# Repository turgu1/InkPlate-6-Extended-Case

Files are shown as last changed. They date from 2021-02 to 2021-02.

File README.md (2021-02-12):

# InkPlate-6-Extended-Case

This is a change to the current InkPlate-6 case to add a small electronic board with push buttons below the mainboard. To do it, I took the original design from e-Radionica and extended a side of it, so the original portion of the case remains unchanged. The `Mechanical CAD` folder contains the complete STEP format design as well as the STL files ready for 3D printing. The `Electronics` folder contains the Gerber files for the preparation of the pc-board, as well as the schematic in PDF. I have used **OnShape** and **KiCAD** to complete this project.

- For the STL files, dimensions are in millimeters. 
- Six buttons must be printed as well as the top and bottom casing. The buttons may have to be adjusted in size depending on the 3D printing results.
- The connection with the MCU23017 is done using wirewrap wires (or a flat cable) that are soldered at both ends using the following configuration (beware that the corresponding buttons numbers are inverted in the sequence):

```
   On the   |     On the     | Corresponding 
Buttons PCB | InkPlate Board |    Button
------------+----------------+---------------
            |                |
   Pin 1    |      GND       |
   Pin 2    |      GPB7      |      U6
   Pin 3    |      GPB6      |      U3
   Pin 4    |      GPB5      |      U5
   Pin 5    |      GPB4      |      U1
   Pin 6    |      GPB3      |      U4
   Pin 7    |      GPB2      |      U2
```

- The squared pad is pin 1.
- On the buttons' pc-board, there is no through-hole, just pads on the surface to solder the wires. This is to ensure that the board will remains flat at the bottom of it's location in the casing.
- The three touch pads on the InkPate-6 pc-board must be disabled, the corresponding signals from the MCU23017 must be diverted to the GPBx pin holes on the main pc-board. This is done by desoldering the current jumpers and soldering them back on the other side. They are located under the following labeling on the board: "Touch pads".
- The GPIOB I/O bits of the MCU23017 corresponding to the GPB2 through GPB7 pins must have their internal pull-up resistor enabled.
- The buttons' pc-board must be of a standard height (1.6 mm). This to ensure proper spacing for the printed buttons. The board must be 'glued' at the bottom of the main casing using two-sided scotch tape. An alternative would be using a very small amount of hot glue on the 4 corners on the top of the buttons' pc-board. This is to permit easy removal in case of problems. 
- The button switches' part number is C&K PTS526 SK15 SMTR2 LFS 5.2x5.2x1.5 mm. They are very common (For exemple, Mouser part # 611-PTS526SK15SMR2L, Digikey Part # CKN12221-1-ND, or other manufacturers equivalent). The 1.5 mm height is important to insure proper spacing for the printed buttons.

The original licensing from e-Radionica remains GPL-3 for their design as well as all supplied files in this project.

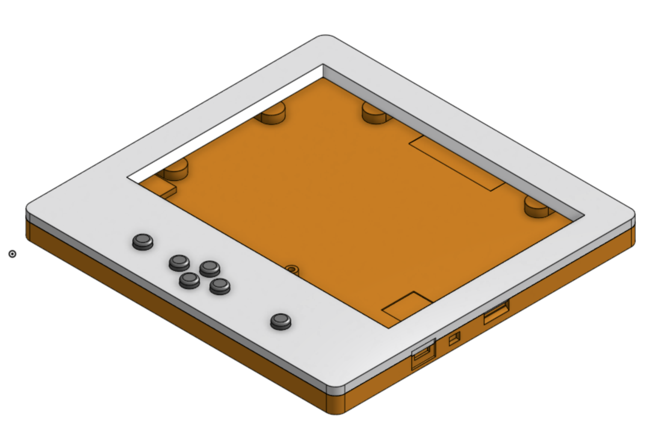
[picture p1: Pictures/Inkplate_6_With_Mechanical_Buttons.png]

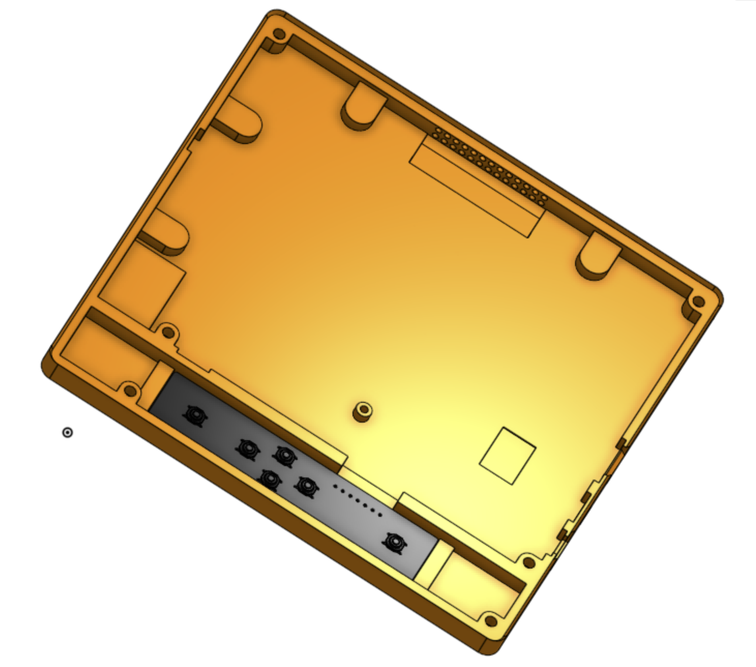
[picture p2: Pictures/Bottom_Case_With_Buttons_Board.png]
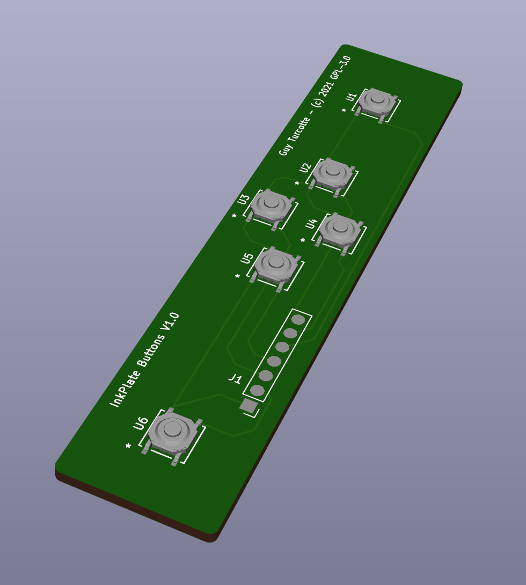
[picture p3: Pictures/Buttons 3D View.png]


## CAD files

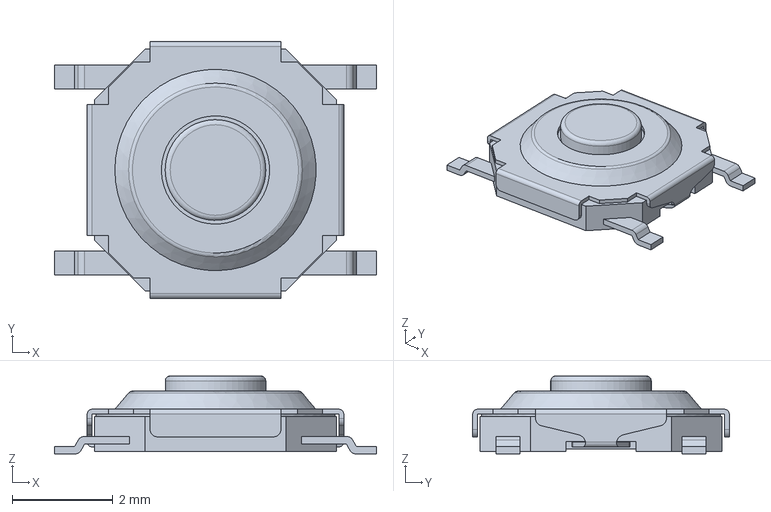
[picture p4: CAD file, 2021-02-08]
Electronics/KiCAD/Parts/3D/PTS526SK15SMTR2LFS.stp
6.40 x 5.10 x 1.55 mm

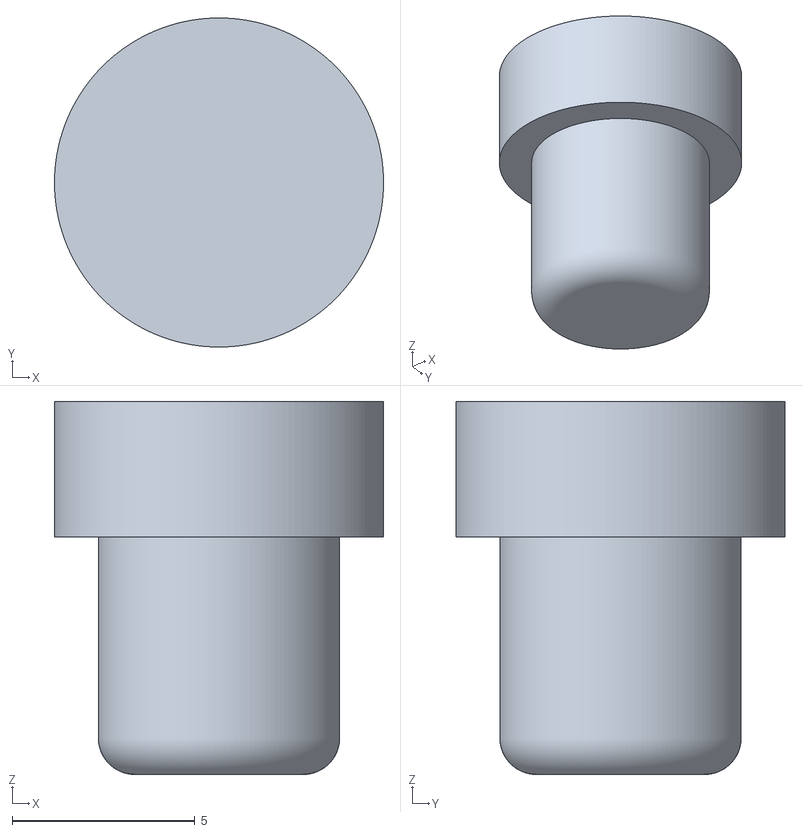
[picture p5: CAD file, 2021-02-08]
Mechanical CAD/Inkplate_6_Button.stl
9.00 x 9.00 x 10.2

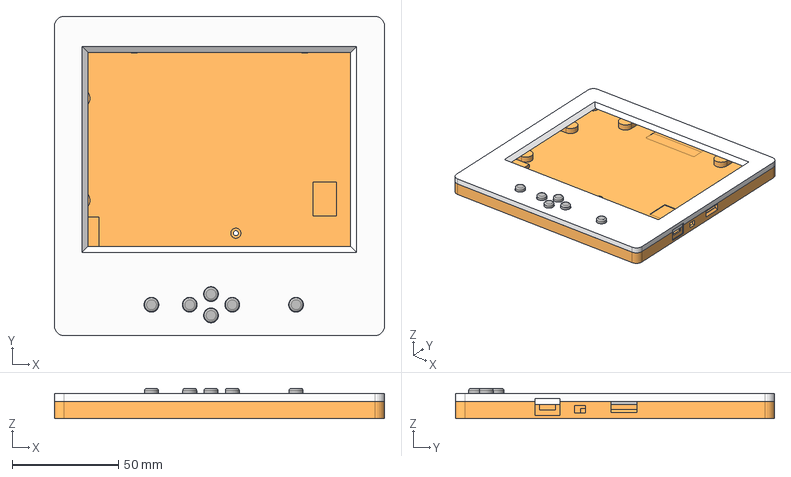
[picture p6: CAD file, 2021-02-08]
Mechanical CAD/Inkplate_6_Case_With_Mechanical_Buttons.step
155.2 x 150.2 x 14.3 mm
Inkplate_6_Case_Enlarged_Bottom
Button x 6
Inkplate_6_Case_Enlarged_Top
U1_1_601E0A63_5
U1_1_601E0A63
Pcb_dfda
U1_1_601E0A63_3
U1_1_601E0A63_4
U1_1_601E0A63_2
U1_1_601E0A63_1

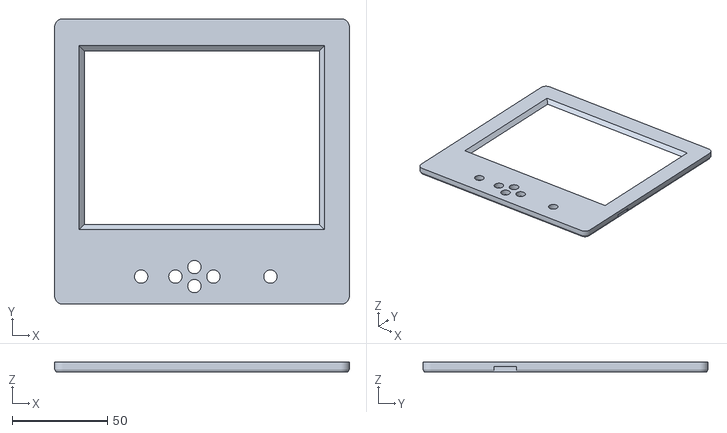
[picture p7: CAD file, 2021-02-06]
Mechanical CAD/Inkplate_6_Case_Enlarged_Top.stl
155.2 x 150.2 x 5.20

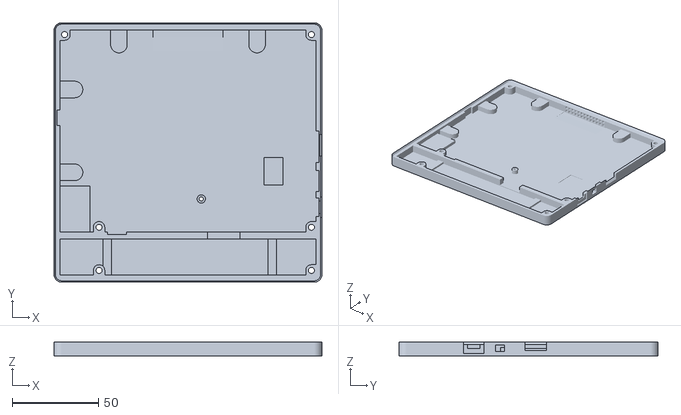
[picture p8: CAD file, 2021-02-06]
Mechanical CAD/Inkplate_6_Case_Enlarged_Bottom.stl
155.2 x 150.2 x 8.00

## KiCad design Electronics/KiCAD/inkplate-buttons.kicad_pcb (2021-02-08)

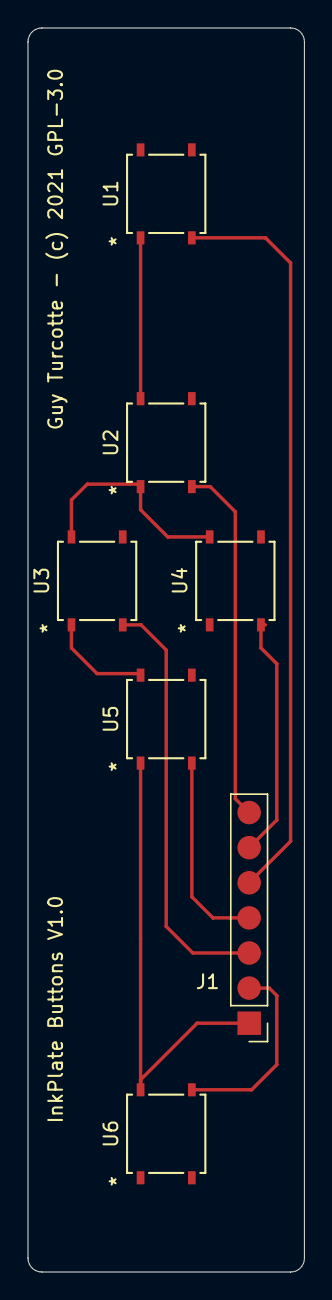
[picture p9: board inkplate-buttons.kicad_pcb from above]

Board: 2 copper layers, 20.0 x 90.0 mm, 7 parts (0 on the bottom side), 10 nets.

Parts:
J1: J1; PinHeader_1x07_P2.54mm_Vertical
U1: U1; PTS526 SK15 SMTR2 LFS
U2: U2; PTS526 SK15 SMTR2 LFS
U3: U3; PTS526 SK15 SMTR2 LFS
U4: U4; PTS526 SK15 SMTR2 LFS
U5: U5; PTS526 SK15 SMTR2 LFS
U6: U6; PTS526 SK15 SMTR2 LFS

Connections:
unnamed: J1.1, U5.1, U6.2
unnamed: J1.2, U6.4
unnamed: J1.3, U3.3
unnamed: J1.4, U5.3
unnamed: J1.5, U1.3
unnamed: J1.6, U4.3
unnamed: J1.7, U2.3
unnamed: U1.1, U2.2
unnamed: U2.1, U3.2, U4.2
unnamed: U3.1, U5.2

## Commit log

2021-02-06 Complete design
    [Inkplate_6_Button.stl, Inkplate_6_Case_Enlarged_Bottom.stl, Inkplate_6_Case_Enlarged_Bottom_Fine.stl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]
2021-02-06 pc-board without through-holes
    [inkplate-buttons-B_Cu.gbr, inkplate-buttons-B_Mask.gbr, inkplate-buttons-Edge_Cuts.gbr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]
2021-02-07 Buttons part # info
2021-02-08 Added KiCAD folder, Updated gerber
    [PTS526SK15SMTR2LFS.stp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]
2021-02-08 3D Button's size adjustment
    [Inkplate_6_Button.stl, Inkplate_6_Case_With_Mechanical_Buttons.step]
2021-02-09 Added drill files
    [inkplate-buttons-NPTH.drl, inkplate-buttons-PTH.drl]
2021-02-12 Update README.md
    Reversed the pins connections to permit the use of a flat cable without folding it.

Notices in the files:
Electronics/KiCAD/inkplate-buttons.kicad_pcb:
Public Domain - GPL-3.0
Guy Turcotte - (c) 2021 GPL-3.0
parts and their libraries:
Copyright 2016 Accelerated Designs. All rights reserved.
